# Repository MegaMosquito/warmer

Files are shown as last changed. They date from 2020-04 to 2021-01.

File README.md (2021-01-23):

# Warmer -- Software For The Ultimate Cup Warmer!

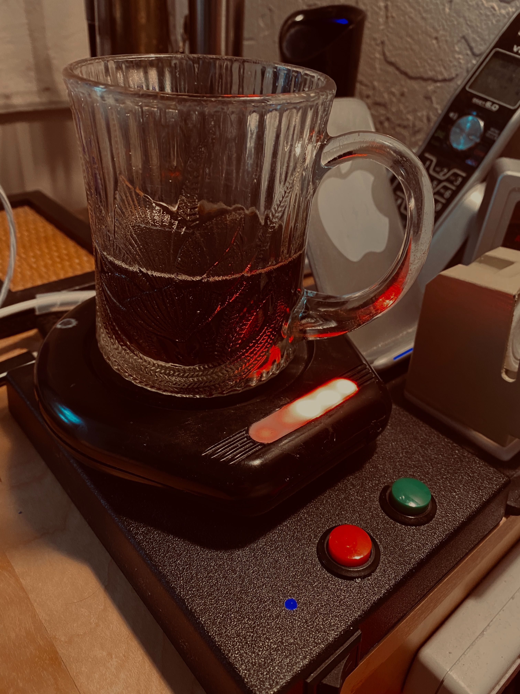
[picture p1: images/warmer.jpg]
Warmer In Use


## Parts

- Mr. Coffee Mug Warmer (https://smile.amazon.com/gp/product/B000CO89T8/ref=ppx_yo_dt_b_search_asin_title?ie=UTF8&psc=1)
- plastic box (I used a Serpac enclosures, 6.88 x 4.88 x .92, but they don't sell that on Amazon any more. I think [this enclosure](https://smile.amazon.com/Serpac-171-Plastic-Enclosure-Length/dp/B00B88CC0Y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) would work well though. Or you could 3D print something.
- small 5V power adapter, like an iPhone charger, and 2 amps is more than enough
- RPi ZeroW
- MCP3008
- 2N2222 transistor
- solid state relay
- Thermistor __ ohms
- two buttons
- a "ready" LED
- 5 neopixels (WS2812) to show time remaining and current temperature
- toggle switch for high voltage power on/off
- power cable and socket
- a few resistors mostly 10K ohms
- wire
- liquid electrical tape (optional...  it's the big black blob covering the high voltage connections in the hardware photo)
- having a 3D printer makes assembly easier, but you could glue stuff in place instead.

## Hardware

The circuitry is shown in the [Fritzing}(http://fritzing.org/home/) document, `circuit.fzz` in this directory.

This is what mine looks like inside:

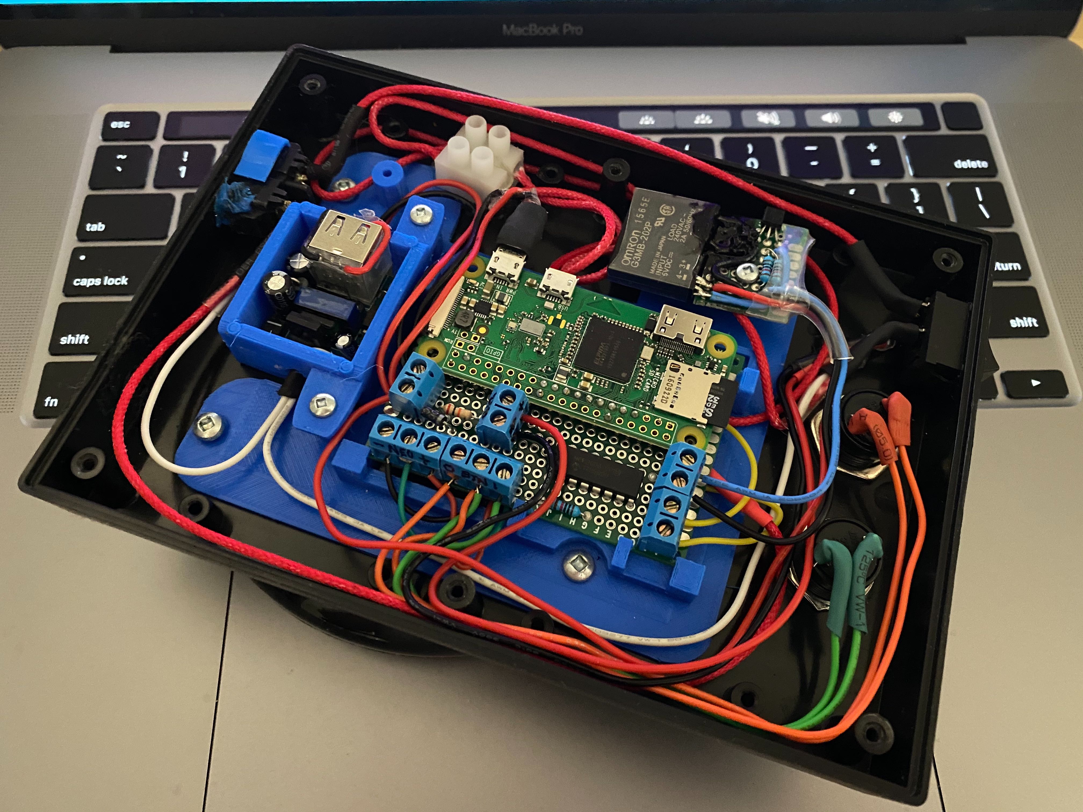
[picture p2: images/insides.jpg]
Warmer Insides


## 3D Models

The 3D models I used for this are here: https://www.tinkercad.com/things/cyHb59UzV8j

## Software

The software monitors the buttons, and acts accordingly to increase or decrease the timeout for the cup warmer. It also monitors the thermistor to know the current temperature of the warming plate (I epoxy-ed the thermistor onto the bottom on the metal heating plate near the heating element). The software also displays the current temperature of the heating plate by using color on the NeoPixel LEDs (red is hottest, through organe, yellow, green. to blue, the coldest). It also shows the time remaining on the NeoPixels by making the leftmost "N" of them much brighter than the others (i.e., same color, but brighter) to indicate "N" time units remaining.

The software also presents a "digital twin" web UI that looks like the real object, and whose buttons and LEDs function the same as the physical object. The digital twin also shows the precise temperature, and the precise amount of time remaining. Here is an image of the web UI in operation:

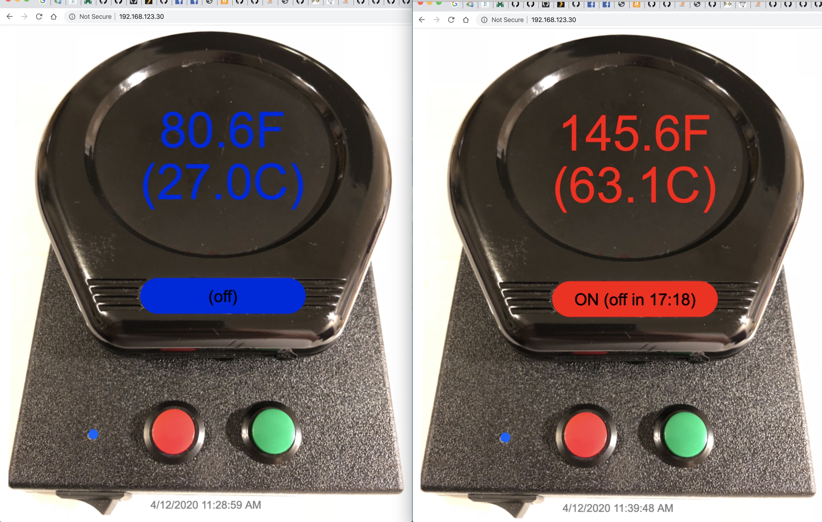
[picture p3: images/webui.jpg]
Warmer Web UI


Create a `/home/pi/git` directory, then clone this repository into there. Enter this directory, then build and run the Docker container:

```
cd /home/pi/git/warmer
make build
make run
```

### Autostart

To make this code always autostart on boot up, add these lines to the bottom of `/etc/rc.local`, but just above the last `exit 0` line.  You could use `sudo nano /etc/rc.local` to edit this system file and then add this:

```
# Start up the beverage warmer program
su pi -c 'cd /home/pi/git/warmer; make run; 2>&1 &'
```

Then reboot.  That's it!

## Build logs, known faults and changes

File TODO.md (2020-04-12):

- the neopixel area size and/or position are not right on iphone (white stripe shows up on right)

- something is screwed up in the web page resizing, when approximately square

- logarithmic scale for the color spectrum (needs to compress the blue end
  because it takes too long to get to hot colors -- well past 45C, which is
  very hot to touch!)

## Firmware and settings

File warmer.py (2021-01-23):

#!/usr/bin/env python3
#
# Glen's drink warmer
#
# Best temperature (for coffee) info:
#   https://driftaway.coffee/temperature/
# GPIO Info:
#   https://sourceforge.net/p/raspberry-gpio-python/wiki/BasicUsage/
#     GPIO.setmode(GPIO.BCM) # or GPIO.BOARD
#     GPIO.setwarnings(False)
#     GPIO.setup(PIN, GPIO.OUT, initial=GPIO.HIGH) # or GPIO.DOWN
#     GPIO.setup(PIN, GPIO.IN,  pull_up_down=GPIO.PUD_UP) # or GPIO.PUD_DOWN
#     GPIO.add_event_detect(PIN, GPIO.FALLING, bouncetime=200) # or GPIO.RISING
#     if GPIO.event_detected(PIN): ...
#     while GPIO.input(PIN) == GPIO.LOW: ...
#     GPIO.output(PIN, GPIO.LOW) # GPIO.HIGH
# ADC (MCP3008) info:
#   https://learn.adafruit.com/raspberry-pi-analog-to-digital-converters/mcp3008
#   https://bitbucket.org/pschow/rpiadctherm/src/d410733214027d58c35c944e75eebf71e56ea5a2/basiclogmcp.py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
#   Hardware SPI:
#     mcp = Adafruit_MCP3008.MCP3008(spi=SPI.SpiDev(0, 0))
#     n = mcp.read_adc(i) # Read raw value from ADC channel 'i'
# Thermisor usage info:
#   https://bitbucket.org/pschow/rpiadctherm/src/
# NeoPixel info:
#   https://learn.adafruit.com/neopixels-on-raspberry-pi/software
#   https://github.com/jgarff/rpi_ws281x
#     color is int32:  (white << 24) | (red << 16)| (green << 8) | blue
#     LED_FREQ_HZ    = 800000 # LED signal frequency in hertz (usually 800khz)
#     LED_DMA        = 10     # DMA channel for generating signal (try 10)
#     LED_BRIGHTNESS = 255    # Set '0' for darkest and 255 for brightest
#     LED_INVERT     = False  # Set 'True' when using NPN transistor level shift
#     LED_CHANNEL    = 0      # set '1' for GPIOs 13, 19, 41, 45 or 53
#     LED_STRIP      = ws.WS2811_STRIP_GRB (or ws.WS2811_STRIP_RGB, or others)
#     neopixels = Adafruit_NeoPixel(LED_COUNT, PIN, LED_FREQ_HZ, LED_DMA, LED_INVERT, LED_BRIGHTNESS, LED_CHANNEL, LED_STRIP)
#     neopixels.begin()
#     neopixels.setPixelColor(pixel_num, color)
#     neopixels.show()
#

# How much time (in minutes) to add/subtract for each button press
TIME_QUANTUM_IN_MINUTES = 10.0

# Maximum time (in minutes) that the timer can be set for
TIME_MAX_IN_MINUTES = 50.0

# How long in seconds after it is off, and cools, before dimming the neopixels
COOLDOWN_PAUSE_IN_SECONDS = (60.0 * 15)

from functools import *
import math
import os
import time
import threading

# Create the web server
from flask import Flask
from flask import send_file
app = Flask(__name__)

# Import the Adafruit NeoPixel library
from neopixel import *

# Import Adafruit SPI library (for hardware SPI)
import Adafruit_GPIO.SPI as SPI

# Import the Adafruit MCP3008 support library
import Adafruit_MCP3008

# Import the GPIO library so python can work with the GPIO pins
import RPi.GPIO as GPIO

# Setup the NeoPixels
NEOPIXEL_PIN   = 18
NEOPIXEL_COUNT = 5
NEOPIXEL_TYPE  = ws.WS2811_STRIP_GRB
neopixels = Adafruit_NeoPixel(NEOPIXEL_COUNT, NEOPIXEL_PIN, 800000, 10, False, 255, 0, NEOPIXEL_TYPE)
neopixels.begin()
neopixels.setBrightness(255);

# Setup hardware SPI for the MCP3008
SPI_PORT   = 0
SPI_DEVICE = 0
mcp3008 = Adafruit_MCP3008.MCP3008(spi=SPI.SpiDev(SPI_PORT, SPI_DEVICE))

# Define a name for the MCP3008 channel where the thermistor is wired
THERMISTOR_CHANNEL = 0

# Configure GPIO library
GPIO.setmode(GPIO.BCM)
GPIO.setwarnings(False)

# Define names for the GPIO pins being used
READY_LED    = 26 # Use only BCM pins #9 or higher (they are low at startup)
BUTTON_RED   = 22
BUTTON_GREEN = 27
WARMER_RELAY = 17

# Configure GPIO pins for input or output
GPIO.setup(READY_LED,    GPIO.OUT, initial=GPIO.LOW)
GPIO.setup(BUTTON_RED,   GPIO.IN,  pull_up_down=GPIO.PUD_UP)
GPIO.setup(BUTTON_GREEN, GPIO.IN,  pull_up_down=GPIO.PUD_UP)
GPIO.setup(WARMER_RELAY, GPIO.OUT, initial=GPIO.LOW)

# Configure edge detection on the two buttons
DEBOUNCE_MSEC = 200
GPIO.add_event_detect(BUTTON_RED,   GPIO.FALLING, bouncetime=DEBOUNCE_MSEC)
GPIO.add_event_detect(BUTTON_GREEN, GPIO.FALLING, bouncetime=DEBOUNCE_MSEC)

# Spectrum of 100 colors from red (hot) through yellow to blue (cold)
colors = [
  0xff0000, 0xfa0500, 0xf50a00, 0xf00f00, 0xeb1400, 0xe61900, 0xe11e00,
  0xdc2300, 0xd72800, 0xd22d00, 0xcd3200, 0xc83700, 0xc33c00, 0xbe4100,
  0xb94600, 0xb44b00, 0xaf5000, 0xaa5500, 0xa55a00, 0xa05f00, 0x9b6400,
  0x966900, 0x916e00, 0x8c7300, 0x877800, 0x827d00, 0x788700, 0x738c00,
  0x6e9100, 0x699600, 0x649b00, 0x5fa000, 0x5aa500, 0x55aa00, 0x50af00,
  0x4bb400, 0x46b900, 0x41be00, 0x3cc300, 0x37c800, 0x32cd00, 0x2dd200,
  0x28d700, 0x23dc00, 0x1ee100, 0x19e600, 0x14eb00, 0x0ff000, 0x0af500,
  0x05fa00, 0x00ff00, 0x00fa05, 0x00f00f, 0x00eb14, 0x00e619, 0x00e11e,
  0x00dc23, 0x00d728, 0x00d22d, 0x00cd32, 0x00c837, 0x00c33c, 0x00be41,
  0x00b946, 0x00b44b, 0x00af50, 0x00aa55, 0x00a55a, 0x00a05f, 0x009b64,
  0x009669, 0x00916e, 0x008c73, 0x008778, 0x00827d, 0x007d82, 0x007887,
  0x00738c, 0x006996, 0x00649b, 0x005fa0, 0x005aa5, 0x0055aa, 0x0050af,
  0x004bb4, 0x0046b9, 0x0041be, 0x003cc3, 0x0037c8, 0x0032cd, 0x002dd2,
  0x0028d7, 0x0023dc, 0x001ee1, 0x0019e6, 0x0014eb, 0x000ff0, 0x000af5,
  0x0005fa, 0x0000ff
]

# This is slightly edited from https://bitbucket.org/pschow/rpiadctherm/src/
def get_temp_celsius(mcp3008, channel):

  value = mcp3008.read_adc(channel)

  volts = (value * 3.3) / 1024 #calculate the voltage
  ohms = ((1/volts)*3300)-1000 #calculate the ohms of the thermististor

  #a, b, & c values from http://www.thermistor.com/calculators.php
  #using curve R (-6.2%/C @ 25C) Mil Ratio X
  a =  0.002197222470870
  b =  0.000161097632222
  c =  0.000000125008328

  #Steinhart Hart Equation
  # T = 1/(a + b[ln(ohm)] + c[ln(ohm)]^3)
  lnohm = math.log1p(ohms) #take ln(ohms)
  t1 = (b*lnohm) # b[ln(ohm)]
  c2 = c*lnohm # c[ln(ohm)]
  t2 = math.pow(c2,3) # c[ln(ohm)]^3
  temp = 1/(a + t1 + t2) #calcualte temperature
  tempc = temp - 273.15 - 4 #K to C
  # the -4 is error correction for bad python math

  #print out debug info
  # print("%4d/1023 => %5.3f V => %4.1f Ω => %4.1f °K => %4.1f °C from adc %d at %s" % (value, volts, ohms, temp, tempc, adc,strftime("%H:%M")))
  return tempc

# Compute running average of temperature over last MEAN_COUNT samples
MEAN_COUNT = 8
# Fill the storage buffer array with this temperature as a start temp
START_TEMP = 25
# Cool python trick to do that initialization
samples = [START_TEMP] * MEAN_COUNT
current_sample = 0
def get_smoothed_temp(mcp3008, channel):
  global current_sample
  samples[current_sample] = get_temp_celsius(mcp3008, THERMISTOR_CHANNEL)
  current_sample = (current_sample + 1) % MEAN_COUNT
  smoothed = reduce(lambda x, y: x + y, samples) / len(samples)
  return smoothed

# Return a dimmed color
DIMMING_MULTIPLIER = 0.10
COOLDOWN_TEMP      = 35.0
FADE_RATE_SEC      = 0.025
FADE_TIME_SEC      = (1 / FADE_RATE_SEC)
# For development
# COOLDOWN_PAUSE_IN_SECONDS = 15.0
def dim_color(color):
  # print("dim color=" + hex(color))
  global just_started
  out_n = 0
  cooldown_multiplier = 1.0
  # print("--> hs=%d, cd_s=%d, c_t=%f" % (heater_state, cooldown_start, current_temp))
  if heater_state == 0 and cooldown_start != 0 and current_temp <= COOLDOWN_TEMP:
    how_long = time.time() - cooldown_start
    # print("--> in cooldown for %d seconds" % (how_long))
    if how_long > COOLDOWN_PAUSE_IN_SECONDS:
      # print("--> after pause of %d seconds" % (COOLDOWN_PAUSE_IN_SECONDS))
      how_long -= COOLDOWN_PAUSE_IN_SECONDS
      cooldown_multiplier = (1.0 - how_long * FADE_RATE_SEC)
      if cooldown_multiplier < 0.0001: cooldown_multiplier = 0.0
      # print("--> cdm=%0.1f" % (cooldown_multiplier))
  for o in (0, 8, 16, 24):
    # print("dim o=" + str(o))
    in_color = (color >> o & 0xff)
    # print("dim in_color=" + hex(in_color))
    out_n += (int(in_color * DIMMING_MULTIPLIER * cooldown_multiplier) << o)
  # print("dim out_n=" + hex(out_n))
  return out_n

# Create a color to match the passed temperature (red => hot, blue => cold)
COLD_BOTTOM     = 25.0
HOT_TOP         = 60.0
def get_color_for_temperature(temp):
  # print("get_color_for_temperature --> %0.2f degrees." % (temp))
  # Note: the drink warmer hardware maxes out around 85C - 90C
  # Anything cooler than COLD_BOTTOM is treated the same as COLD_BOTTOM
  if temp < COLD_BOTTOM: temp = COLD_BOTTOM
  # Anything hotter than HOT_TOP is treated the same as HOT_TOP
  if temp > HOT_TOP: temp = HOT_TOP
  # Normalize the temperature to range 0..99
  n = int(99 * (temp - COLD_BOTTOM) / (HOT_TOP - COLD_BOTTOM))
  # Get color from the 100-color spectrum array
  c = colors[99 - n]
  global temp_color
  temp_color = c
  r = (c & 0xff0000) >> 16
  g = (c & 0x00ff00) >> 8
  b = (c & 0x0000ff)
  #print("--> c=0x%06x, r=0x%02x, g=0x%02x, b=0x%02x" % (c, r, g, b))
  out_color = Color(r, g, b)
  # print("get_color_for_temperature <-- " + hex(out_color))
  return out_color

# Update the NeoPixels with color for temp, and brightnes for time remaining
SECONDS_PER_PIXEL = (60 * TIME_QUANTUM_IN_MINUTES)
def update_neopixels(temp, time_remaining_sec):
  # print("update_neopixels(temp=%0.1fC/%0.1fF, sec=%0.2f)" % (temp, temp * 9.0 / 5.0 + 32, time_remaining_sec))
  if time_remaining_sec < 0:
    time_remaining_sec = 0
  pixels_remaining = int(0.5 + time_remaining_sec / SECONDS_PER_PIXEL)
  # print(" -- pixels_remaining = %d" % (pixels_remaining))
  color = get_color_for_temperature(temp)
  num = neopixels.numPixels()
  for i in range(num):
    # Make sure one pixel stays bright if any more than a millisecond remains
    if i < pixels_remaining or (i == 0 and time_remaining_sec > 0.001):
      # print("(T) --> setPixelColor(%d, 0x%x)" % (i, color))
      # Oops! I foolishly glued pixel strip backwards, so must invert 'i' here!
      neopixels.setPixelColor(NEOPIXEL_COUNT - i - 1, color)
    else:
      # print("(F) --> setPixelColor(%d, 0x%x (dim))" % (i, dim_color(color)))
      # Oops! I foolishly glued pixel strip backwards, so must invert 'i' here!
      neopixels.setPixelColor(NEOPIXEL_COUNT - i - 1, dim_color(color))
    time.sleep(0.01) # Need to pause briefly between settings
    neopixels.show()

# Control the modifications to the off_time variable
def change_off_time(delta):
  global off_time
  # print("--> change_off_time(%0.2f)  [%0.2f]" % (delta, off_time - time.time()))
  if off_time < time.time():
    if delta > 0:
      off_time = time.time() + delta
  else:
    if delta > 0:
      off_time += delta
    elif delta < 0 and off_time + delta <= time.time():
      off_time = time.time() - 1
    else:
      off_time += delta
  # Enforce the timer maximum
  now = time.time()
  max = now + (TIME_MAX_IN_MINUTES * 60.0)
  if off_time > max:
    off_time = max
  # print("<-- change_off_time(%0.2f)  [%0.2f]" % (delta, off_time - time.time()))

# Handle button presses
def press_button(which):
  if (which == "red"):
    #print("RED Button")
    change_off_time(TIME_QUANTUM_IN_MINUTES * 60.0)
  elif (which == "green"):
    #print("GREEN Button")
    change_off_time(- TIME_QUANTUM_IN_MINUTES * 60.0)

# Shutdown the Heater, the NeoPixels, etc.
def cleanup():
  # Reset the off timer
  global off_time
  off_time = time.time() - 1
  # Turn off the warmer relay
  GPIO.output(WARMER_RELAY, GPIO.LOW)
  # Turn off the "ready" LED
  GPIO.output(READY_LED, GPIO.LOW)
  # Turn off all of the NeoPixels
  for i in range(neopixels.numPixels()):
    neopixels.setPixelColor(i, Color(0,0,0))
    time.sleep(0.01) # Need to pause briefly between settings
    neopixels.show()
  # For cleanliness, move to a new line in the output after the ^C
  print('')

# Update the global current_state, used by the REST srver
def update_current_state():
  global current_state
  secs = max(0, off_time - time.time())
  c_s = '{'
  c_s += ('"temp_c":%0.1f,' % (current_temp))
  c_s += ('"temp_color":"#%06x",' % (temp_color))
  c_s += ('"time_sec":%0.1f' % (secs))
  c_s += '}'
  current_state = c_s
  # print('current_state = "' + current_state + '"')

# This is all the code that implements the Flask web server
web_server = None
def start_web_server():
  # app.run(debug=False, use_reloader=False, host='0.0.0.0')
  app.run(debug=True, use_reloader=False, host='0.0.0.0')
@app.route('/favicon.ico', methods=['GET'])
def send_favicon():
  return send_file('/usr/src/app/favicon.ico')
@app.route("/images/<filename>", methods=['GET'])
def send_image(filename):
  filename = os.path.basename(filename)
  return send_file('/usr/src/app/images/' + filename)
@app.route("/<filename>", methods=['GET'])
def send_other(filename):
  filename = os.path.basename(filename)
  return send_file('/usr/src/app/html/' + filename)
@app.route("/state", methods=['GET'])
def send_state():
  return '{"state":' + current_state + '}'
@app.route("/", methods=['GET'])
def send_root():
  return send_file('/usr/src/app/html/index.html')
@app.route('/button/red', methods=['POST'])
def press_button_red():
  press_button('red')
  return ''
@app.route('/button/green', methods=['POST'])
def press_button_green():
  press_button('green')
  return ''

# Global variables and main program
current_state = None
off_time = time.time() - 1
current_temp = 0
temp_color = 0x000000
heater_state = 0
cooldown_start = 0
def main():

  try:                                                                        

    # Initialize the global current_state, used by the REST srver
    update_current_state()

    # Start the web server in a thread
    global web_server
    web_server = threading.Thread(target=start_web_server)
    # The line below ensures the web server thread exits when main exits
    web_server.setDaemon(True)
    web_server.start()

    # Reduce console noise
    import logging
    log = logging.getLogger('werkzeug')
    log.setLevel(logging.ERROR)

    # Turn on the "ready" indicator
    GPIO.output(READY_LED, GPIO.HIGH)

    global heater_state
    heater_state = 0
    just_started = True
    while True:                                                             

      # Get the smoothed temperature reading
      temp_smoothed = get_smoothed_temp(mcp3008, THERMISTOR_CHANNEL)
      # print("The temperature is %0.2f degrees celsius." % (temp_smoothed))

      # Adjust the temperature if appropriate
      global current_temp
      if math.fabs(current_temp - temp_smoothed) > 0.5:
        current_temp = temp_smoothed

      if GPIO.event_detected(BUTTON_RED):
        press_button("red")

      if GPIO.event_detected(BUTTON_GREEN):
        press_button("green")

      # Operate the relay
      now = time.time()
      if off_time > now:
        #if heater_state == 0: print("--> ON (off in %0.2fs)" % (off_time - now))
        GPIO.output(WARMER_RELAY, GPIO.HIGH)
        heater_state = 1
      else:
        global cooldown_start
        if just_started:
          just_started = False
          cooldown_start = time.time() - (COOLDOWN_PAUSE_IN_SECONDS + FADE_TIME_SEC + 1)
          # print("--> OFF (at startup)")
        elif heater_state != 0:
          cooldown_start = time.time()
          # print("--> OFF")
        GPIO.output(WARMER_RELAY, GPIO.LOW)
        heater_state = 0

      # Update state every loop even if user does nothing, because time flies!
      update_current_state()

      # Update neopixels ever loop too
      update_neopixels(temp_smoothed, max(0, off_time - time.time()))

      # Brief pause before repeating
      # time.sleep(LOOP_SLEEP_MSEC / 1000.0)
                                                                                
  except KeyboardInterrupt:
    cleanup()

  # For any failure at all, shutdown everything (especially the warmer relay!
  except:                                                   
    import traceback
    traceback.print_exc()
    cleanup()

  # Exit cleanly (need this to close the web server thread
  exit(0)

if __name__ == '__main__':
  main()

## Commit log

2020-04-12 First substantive commit.
    [circuit.fzz]
2020-04-12 Link to the enclosure box.
2021-01-23 Correct path to index file. Add auto-restart.
    [warmer.py]
